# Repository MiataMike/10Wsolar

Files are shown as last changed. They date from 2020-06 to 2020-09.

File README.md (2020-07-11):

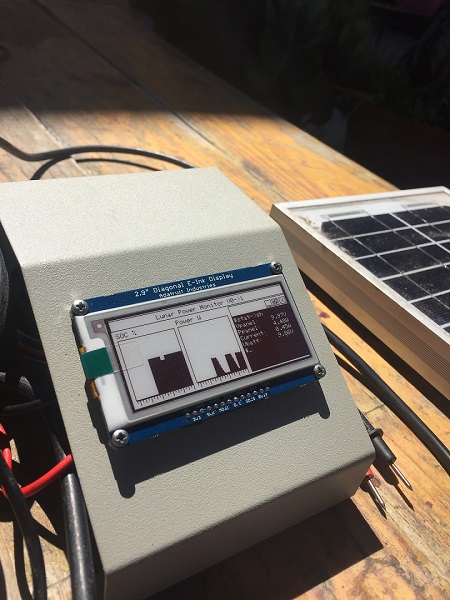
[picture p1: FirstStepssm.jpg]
image of charger


# 10Wsolar
This project is a solar power converter for charging the 12V battery in my truck with a 10W solar panel I got from amazon. 
## MPPT control
Solar panels deliver different currents at different voltages, in the specs below we can see it's 0A @ 21V and .57A @ 17.5V.
 The power of the first is 0W and the second is 10W, so we can get more power from our panel if we operate at the optimal voltage.
 The microcontroller will vary the duty cycle of the buck converter, lowering the voltage of the panel from between open circuit voltage and the battery's voltage.
 Additionally, I don't want to overcharge the battery (It's currently directly connected and who knows what rate it's working at) so I'll add some control logic to trickle charge the battery.
 Since I'm a data geek, I've added an SD card so I can monitor the panel's performance over time, and the truck's (hopefully full) state of charge.
 # Parts
 
 ## Voltage sensing
 The voltage sensing is reading the panel's voltage and the battery's voltage. The panel voltage is used in the control loop to calculate the power we're pulling from the panel. The battery voltage is measured to check state of charge.
 I've used high value resistors because this current draw is constant, even at night. The filtering is agressive so I'll need to slow down my control loop and watch out for oscillation.

 ## CPU
 I've wanted to get my feet wet with ARM processors after taking a class on them in college. This processor has a small form factor and low power to boost efficiency.
 
## Buck converter
Thanks TI for making the buck converter component datasheet! I've chosen values from the panel specs below, but added a much larger inductor in case my frequency needs to go down, or I want to convert much smaller currents
I've added a backup diode in case the syncronous switching doesn't work out. 
 
## current sensing
TI also makes a great chip for monitoring the voltage across a shunt. Doing this with a single ended ADC would be a pain, and it comes with built in filtering and gain. 

## 3.3V converter
Thanks Collin Winans, I'm using his design for a 3.3V buck converter to supply power to the circuit. Most of the symbols in this design are his too.
This should be a very efficeint option since we're stepping down all the way from 12V, which would be a lot of energy to burn in a linear regulator.

## MPPT algorithm
At first, I may just close the top switch and collect data on what the panel does when it's connected directly. This would give me a baseline
From there, I would write code that calculates and optimizes the power coming from the panel. 
The hill climbing algorithm that changes direction every time it detects a drop in power should do nicely. 
Some other features I'd like to add are:
- sleeping at night
- characterizing the panel (V vs A)
- voltage cutoff and derating based on battery voltage
- bitcoin mining to prevent overcharge (not on a Cortex-F0, but still)

## panel specs
- 21V open circuit
- 17.5V @peak power
- .57A 	@peak power
- stylish aluminum frame

# Routing considerations

## Current carrying
I'm designing this around a 1A nominal current, which is more than the 10W panel should put out on the 12V bus. Using a trace width calculator w/ 10C rise @ 1oz/ft^2, I get 11mil traces minimum. Lower trace resistance decreases losses, so this is a minimum

## Overall layout
when designing power electronics, it's important to imagine the current path and ground returns. Can you tell which way I routed it?

## Coil placement
 Big Bob is on the top, a horizontally mounted toroidal coil. On the bottom there's a bobbin wound inductor for the 5V supply.
 The direction of the magnetic field around the bobbin creates a toroid whose axis is normal to the board while the toroid creates a field in a circle along the plane of the board.
 Having these fields at 90 degrees should minimize coupling.

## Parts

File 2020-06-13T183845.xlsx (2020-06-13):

Index | Quantity | Part Number | Manufacturer Part Number | Description | Customer Reference | Available | Backorder | Unit Price | Extended Price USD
1 | 1 | M8843-ND | 2319-H-RC | FIXED IND 390UH 5A 72 MOHM TH |  | 1 | 0 | 3.99 | 3.99
2 | 2 | SSM3K329RLFCT-ND | SSM3K329R,LF | MOSFET N CH 30V 3.5A 2-3Z1A |  | 2 | 0 | 0.41 | 0.82
3 | 1 | LTC1255CS8#PBF-ND | LTC1255CS8#PBF | IC GATE DRVR HIGH-SIDE 8SOIC |  | 1 | 0 | 7.61 | 7.61
4 | 2 | AS-210MPD-ND | AS-210 | PANEL MOUNT DIN SOCKET ANTI-SPLA |  | 2 | 0 | 7.81 | 15.62
5 | 10 | 118-CR0805-JW-203ELFCT-ND | CR0805-JW-203ELF | RES SMD 20K OHM 5% 1/8W 0805 |  | 10 | 0 | 0.018 | 0.18
6 | 10 | RMCF0805JT120KCT-ND | RMCF0805JT120K | RES 120K OHM 5% 1/8W 0805 |  | 10 | 0 | 0.019 | 0.19
7 | 10 | 399-4925-1-ND | C0805C106K8PACTU | CAP CER 10UF 10V X5R 0805 |  | 10 | 0 | 0.117 | 1.17
8 | 1 | 296-41286-1-ND | LM22674MRX-5.0/NOPB | IC REG BUCK 5V 500MA 8SOPWR |  | 1 | 0 | 2.92 | 2.92
9 | 10 | 490-12457-1-ND | GRT31CR61H106ME01L | CAP CER 10UF 50V X5R 1206 |  | 10 | 0 | 0.349 | 3.49
10 | 2 | 732-11924-1-ND | 870235675007 | WCAP-PT5H ALUMINUM POLYMER CAP |  | 2 | 0 | 2.01 | 4.02
11 | 2 | RL12T.010JCT-ND | RL1220T-R010-J | RES 0.01 OHM 5% 1/4W 0805 |  | 2 | 0 | 0.36 | 0.72
12 | 1 | 296-46096-1-ND | INA225AIDGKR | IC MONITOR PWR/CUR BIDIR 8VSSOP |  | 1 | 0 | 2.04 | 2.04
13 | 2 | RNCF0805AKT10R0CT-ND | RNCF0805AKT10R0 | RES 10 OHM 0.05% 1/8W 0805 |  | 2 | 0 | 0.97 | 1.94
14 | 2 | 399-1159-1-ND | C0805C103K1RACTU | CAP CER 10000PF 100V X7R 0805 |  | 2 | 0 | 0.1 | 0.20
15 | 1 | SDR1105-151KLCT-ND | SDR1105-151KL | FIXED IND 150UH 1.2A 500MOHM SMD |  | 1 | 0 | 0.97 | 0.97
16 | 2 | 1727-3848-1-ND | PMEG6010CEH,115 | DIODE SCHOTTKY 60V 1A SOD123F |  | 2 | 0 | 0.42 | 0.84
17 | 1 | 609-5505-ND | 68000-113HLF | CONN HEADER VERT 13POS 2.54MM |  | 1 | 0 | 0.73 | 0.73
18 | 1 | 1528-1963-ND | 1952 | JUMPER WIRE M TO F 12" 28AWG |  | 1 | 0 | 3.95 | 3.95
19 | 1 | 1528-1028-ND | 1028 | 2.9" RED/BLACK/WHITE EINK DSPLY |  | 1 | 0 | 34.95 | 34.95
20 | 1 | 1528-2385-ND | 2756 | TEENSY 3.2 K20 EVAL BRD |  | 1 | 0 | 24.94 | 24.94
21 | 2 | S7012-ND | PPTC141LFBN-RC | CONN HDR 14POS 0.1 TIN PCB |  | 2 | 0 | 0.91 | 1.82
22 | 1 | CN645R-25-ND | 1569-16-1-0500-004-1-TS | HOOK-UP STRND 16AWG 300V RED 25' |  | 1 | 0 | 9.52 | 9.52
23 | 1 | CN642B-25-ND | 1569-16-1-0500-001-1-TS | HOOK-UP STRND 16AWG 300V BLK 25' |  | 1 | 0 | 9.52 | 9.52
24 | 10 | A27824CT-ND | 3-350819-2 | CONN QC RCPT 14-16AWG 0.250 |  | 10 | 0 | 0.255 | 2.55
25 | 10 | WM17242-ND | 0192030470 | CONN RING CIRC 14-16AWG #8 CRIMP |  | 10 | 0 | 0.129 | 1.29
26 | 3 | WM13853-ND | 0192030388 | CONN RING CIRC 14-16AWG #10 |  | 3 | 0 | 0.14 | 0.42
27 | 3 | ED1501-ND | ED550/2DS | TERM BLK 2P TOP ENTRY 3.5MM PCB |  | 3 | 0 | 1.06 | 3.18
28 | 1 | HM3090-ND | 1456CE3WHBU | CONSOLE ALUMINUM 4.18"L X 5.75"W |  | 1 | 0 | 23.65 | 23.65
29 | 1 | RPC3080-ND | HG-17 | GROMMET 0.315" ELASTOMER BLACK |  | 1 | 0 | 0.68 | 0.68
30 | 4 | 36-400-ND | 400 | ROUND SPACER #4 ALUMINUM 3/8" |  | 4 | 0 | 0.18 | 0.72

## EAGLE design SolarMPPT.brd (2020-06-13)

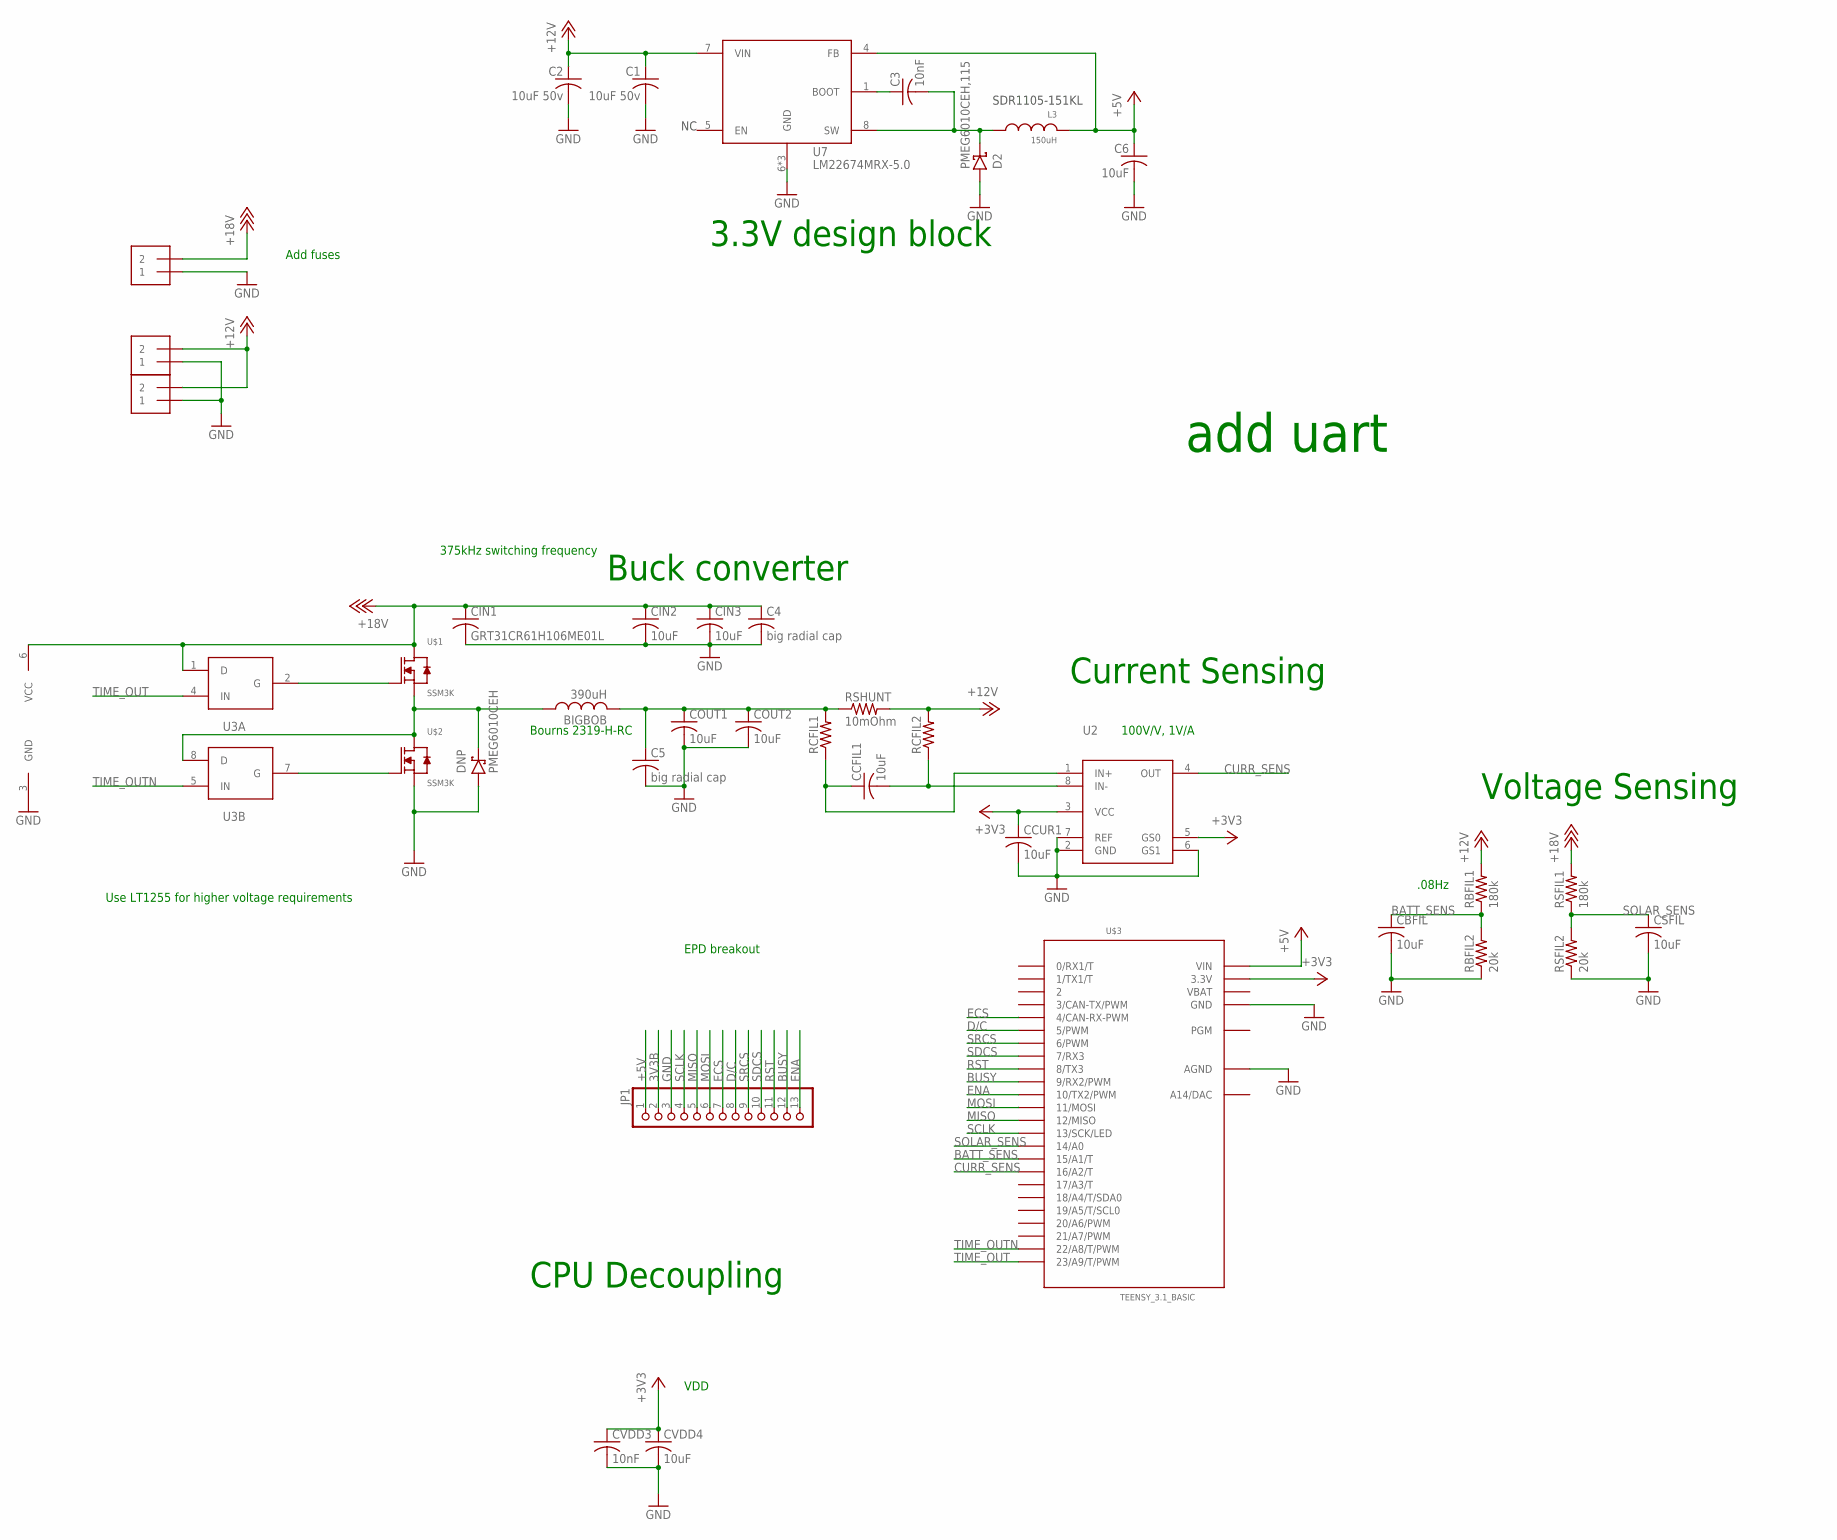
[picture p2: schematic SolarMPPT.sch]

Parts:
BIGBOB: 390uH; TJ6-U2
C1: 10uF 50v; C0805; PARTNO UMK212BJ105KG-T
C2: 10uF 50v; C1206; PARTNO GRM31CR71H475KA12L
C3: 10nF; C0805; PARTNO GRM216R71H103KA01D
C4, C5: big radial cap; C050-024X044
C6: 10uF; C0805; PARTNO GRM21BR61E106KA73L
CBFIL: 10uF; C0805
CCFIL1: 10uF; C0805
CCUR1: 10uF; C0805
CIN1: GRT31CR61H106ME01L; C1206
CIN2, CIN3: 10uF; C1206
COUT1, COUT2: 10uF; C1206
CSFIL: 10uF; C0805
CVDD3: 10nF; C0805
CVDD4: 10uF; C0805
D2: PMEG6010CEH,115; SOD-123; PARTNO PMEG6010CEH115
DNP: PMEG6010CEH; SOD-123
J2, J3, J6: 1X2-3.5MM
JP1: PINHD-1X13; 1X13
L3: 150uH; SDR1105; PARTNO SDR1105-151KL
RBFIL1: 180k; R0805
RBFIL2: 20k; R0805
RCFIL1, RCFIL2: R-US_R0805; R0805
RSFIL1: 180k; R0805
RSFIL2: 20k; R0805
RSHUNT: 10mOhm; R1206
U2: INA225VSSOP; VSSOP-8
U3: LTC1155; LT-SOL8
U7: LM22674MRX-5.0; SOIC-8-POWERPAD; PARTNO LM22674MRX-5.0/NOPB
U$1, U$2: SSM3K; SOT-23-MOSFET
U$3: TEENSY_3.1_BASIC

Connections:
3V3B: JP1.2
+3V3: CCUR1.1, CVDD3.1, CVDD4.1, U2.3 (VCC), U2.5 (GS0), U$3.3.3V, U$3.3.3V1 (3.3V)
+5V: C6.1, JP1.1, L3.P$1, U7.4 (FB), U$3.VIN
+12V: C1.1, C2.1, J2.2, J3.2, RBFIL1.2, RCFIL2.2, RSHUNT.2, U7.7 (VIN)
+18V: C4.1, CIN1.1, CIN2.1, CIN3.1, J6.2, RSFIL1.2, U3.1 (D), U3.6 (VCC), U$1.D
BATT_SENS: CBFIL.1, RBFIL1.1, RBFIL2.2, U$3.15/A1 (15/A1/T)
BOOT_5V2: C3.1, U7.1 (BOOT)
BUSY: JP1.12, U$3.9 (9/RX2/PWM)
CURR_SENS: U2.4 (OUT), U$3.16/A2 (16/A2/T)
D/C: JP1.8, U$3.5 (5/PWM)
ECS: JP1.7, U$3.4 (4/CAN-RX-PWM)
ENA: JP1.13, U$3.10 (10/TX2/PWM)
GND: C1.2, C2.2, C4.2, C5.2, C6.2, CBFIL.2, CCUR1.2, CIN1.2, CIN2.2, CIN3.2, COUT1.2, COUT2.2, CSFIL.2, CVDD3.2, CVDD4.2, D2.A, DNP.A, J2.1, J3.1, J6.1, JP1.3, RBFIL2.1, RSFIL2.1, U2.2 (GND), U2.6 (GS1), U2.7 (REF), U3.3 (GND), U7.6 (GND), U7.PAD (GND), U7.PAD1 (GND), U$2.S, U$3.AGND, U$3.GND, U$3.GND1 (GND)
MISO: JP1.5, U$3.12 (12/MISO)
MOSI: JP1.6, U$3.11 (11/MOSI)
unnamed: U3.2 (G), U$1.G
unnamed: CCFIL1.2, RCFIL2.1, U2.8 (IN-)
unnamed: CCFIL1.1, RCFIL1.1, U2.1 (IN+)
unnamed: BIGBOB.1, DNP.K, U3.8 (D), U$1.S, U$2.D
unnamed: U3.7 (G), U$2.G
unnamed: BIGBOB.2, C5.1, COUT1.1, COUT2.1, RCFIL1.2, RSHUNT.1
RST: JP1.11, U$3.8 (8/TX3)
SCLK: JP1.4, U$3.13 (13/SCK/LED)
SDCS: JP1.10, U$3.7 (7/RX3)
SOLAR_SENS: CSFIL.1, RSFIL1.1, RSFIL2.2, U$3.14/A0
SRCS: JP1.9, U$3.6 (6/PWM)
SW_5V2: C3.2, D2.K, L3.P$2, U7.8 (SW)
TIME_OUT: U3.4 (IN), U$3.23/A9 (23/A9/T/PWM)
TIME_OUTN: U3.5 (IN), U$3.22/A8 (22/A8/T/PWM)
VBAT: U$3.VBAT

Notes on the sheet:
VDD
.08Hz
100V/V, 1V/A
375kHz switching frequency
Use LT1255 for higher voltage requirements
Bourns 2319-H-RC
Voltage Sensing
Current Sensing
CPU Decoupling
3.3V design block
Buck converter
SDR1105-151KL
Add fuses
add uart
EPD breakout

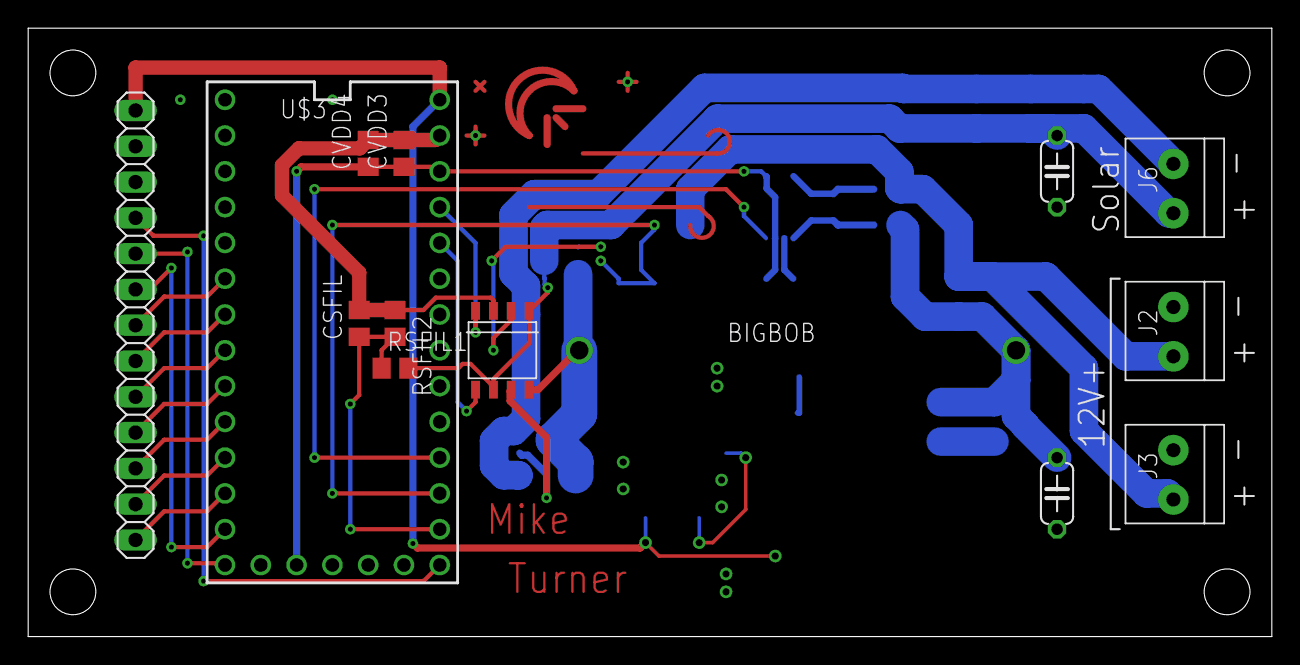
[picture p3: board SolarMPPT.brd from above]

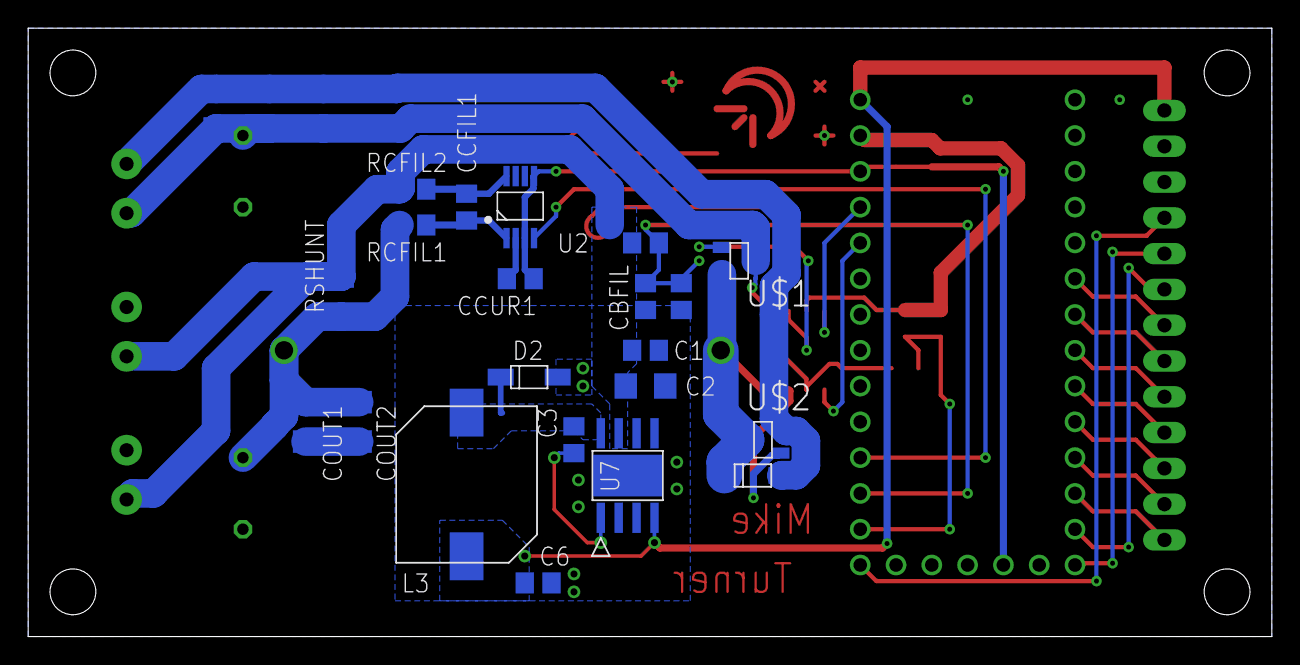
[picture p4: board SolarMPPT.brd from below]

Board: 2 copper layers, 88.3 x 43.2 mm, 38 parts (24 on the bottom side), 28 nets.

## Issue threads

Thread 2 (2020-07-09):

Current reads .02 when no current is flowing

MiataMike, 2020-07-09:

MiataMike, 2020-07-11:
Slam dunk of a fix, but I'll wait to close this for semantics' sake

MiataMike, 2020-07-25:
Current goes to 0 at night, closing
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

Closed 2020-07-25.

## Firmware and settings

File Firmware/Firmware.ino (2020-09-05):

#include <Adafruit_GFX.h>    // Core graphics library
#include "Adafruit_EPD.h"
#include "gauges.h"
#include "reading.h"
#include "control.h"
#include "math.h"
#include "TimeLib.h"
#include <SD.h>


#define EPD_CS      4
#define EPD_DC      5
#define SRAM_CS     6
#define EPD_RESET   8 // can set to -1 and share with microcontroller Reset!
#define EPD_BUSY    9 // can set to -1 to not use a pin (will wait a fixed delay)
#define SD_CS       7

int chartData1[85];
String chartTitle1 = "Battery V";
int chartData2[84];
String chartTitle2 = "Power W";
Adafruit_IL0373 display(296, 128, EPD_DC, EPD_RESET, EPD_CS, SRAM_CS, EPD_BUSY);
Graph SOCgraph(5, 32, 86,86,"SOC %", &display);
Graph POWgraph(96, 32, 86,86, "Power W", &display);
float Vbatt = -1;
float Vpan = -1;
float Abatt = -1;

int duty = 0;

File datalog;

elapsedMillis timeSinceDisplay;
#define DisplayPeriodMillis 60000*5
elapsedMillis timeSinceCmd;
#define CmdPeriodMillis 100 // TODO tune this

#define hr 9
#define minute 21
#define sec 0
#define day 20
#define month 8
#define yr 2020



void setup() {
  //setTime(hr,minute,sec,day,month,yr);Soldered on RTC, Synced with NTP
  // put your setup code here, to run once:
  Serial.begin(9600);
  analogReadRes(16);
  delay(1000);
  
  for(int i = 0; i<84; i++)
  {
    chartData1[i] = 0;
    //chartData1[i] = 42*cos(i*6.28/42)+42;
    //Serial.println(chartData1[i]);
  }
    for(int i = 0; i<84; i++)
  {
    chartData2[i] = 0;
    //chartData2[i] = 42*sin(i*6.28/42)+42;
    //Serial.println(chartData2[i]);
  }
  SOCgraph.updateData(chartData1);
  POWgraph.updateData(chartData2);

  display.begin();
  SD.begin(SD_CS);
  initControl();
}

void loop() {
  // put your main code here, to run repeatedly:

while(1)
{
  if(timeSinceDisplay > DisplayPeriodMillis)
  {
    timeSinceDisplay -= DisplayPeriodMillis;
    SOCgraph.updateData2(84, (int)(Vbatt * 84 / 15.0));
    POWgraph.updateData2(84, (int)(Vbatt * Abatt * 84/13.0));

    display.clearBuffer();
    drawWindow(&display);
    SOCgraph.draw();
    POWgraph.draw();
    drawTerminal(Vbatt, Vpan, Abatt, &display);
    display.display();
    datalog = SD.open("datalog.csv", FILE_WRITE);
    if (datalog)
    {// Time, Vpanel, Abatt, Vbatt, duty
      datalog.print(now());
      datalog.print(",");
      datalog.print(Vpan);
      datalog.print(",");
      datalog.print(Abatt);
      datalog.print(",");
      datalog.print(Vbatt);
      datalog.print(",");
      datalog.println(duty);  
      datalog.close();
    }
  }

  if(timeSinceCmd > CmdPeriodMillis)
  {
    timeSinceCmd -= CmdPeriodMillis;
    Vpan = readSolar();
    Abatt = readCurr();
    Vbatt = readBatt();
    Serial.println(Vpan);
    Serial.println(Abatt);
    Serial.println(Vbatt); 
    Serial.println(duty);
    Serial.println("_________");
    duty = highPower(Vbatt, Abatt, duty);
    analogWrite(HighsidePin, duty);

  }
  
}
}//end loop()

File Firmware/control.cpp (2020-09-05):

#include "control.h"
#include "arduino.h"

int initControl()
{
  pinMode(HighsidePin, OUTPUT);
  analogWriteResolution(6);
  analogWriteFrequency(HighsidePin, 1500000);
	analogWrite(HighsidePin, 0);
	//digitalWrite(HighsidePin, HIGH);
	return 0;
}

#define Vcutoff 14.4
void updateControl(float Vbus)
{
	if (Vbus < Vcutoff)
	{
		digitalWrite(HighsidePin, HIGH); //allow charging
	}
	else
	{
		digitalWrite(HighsidePin, LOW);// turn off in all other cases
	}
	return;
}

int highPower(float Vbus, float Abatt, int duty)
{
  static float lastPow = 0; // filter this?
  static bool upLast = false; // hillclimbing state
  if(Abatt < .02){return dutyUp(duty);} // keep it from getting stuck
  else if(Vbus > 13.7){return dutyDown(duty);}// don't overcharge
  else if(lastPow > Vbus*Abatt)//if it got worse
  {
    if(upLast){duty = dutyDown(duty);}//and it was going up, go down
    else{duty = dutyUp(duty);}        //if it was going down, go up
    upLast = !upLast;             //change direction
  }
  else                            //if it got better
  {
    if(upLast){duty = dutyUp(duty);}  //keep going up
    else{duty = dutyDown(duty);}      //GJ 
  }
  lastPow = Vbus*Abatt;
  return duty;
}


//Bounds checking I didn't want to include in the function
#define dutyMin 0 //so it doesnt get lost
int dutyDown(int duty)
{
  if (duty <= dutyMin)
  {
    duty = dutyMin;
  }
  else{duty--;}
  return duty;
}

#define dutyMax 64
int dutyUp(int duty)
{
  if (duty >= dutyMax)
  {
    duty = dutyMax;
  }
  else{duty++;}
  return duty;
}

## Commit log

2020-05-30 Adding eagle schematic and Buck calculator
    [SolarMPPT.sch, TI_Buck calc.xlsx]
2020-05-30 Added LT1255 gate driver and MOSFETs
    [SolarMPPT.sch]
2020-05-30 finished Buck component selection
    [SolarMPPT.sch]
2020-05-30 Added decoupling caps, cleaned up schematic, ready for review
    [SolarMPPT.sch]
2020-05-30 Updated 'documentation' and spreadsheet
    [TI_Buck calc.xlsx]
2020-05-31 created brd file and sorted into categories
    [SolarMPPT.brd, SolarMPPT.sch]
2020-05-31 placed components in rough location. Might remap ADC pins for routing
    [SolarMPPT.brd]
2020-05-31 Did power routing and added terminals
    [SolarMPPT.brd, SolarMPPT.sch]
2020-06-07 added teensy, removed SD
    [SolarMPPT.brd, SolarMPPT.sch]
2020-06-07 removed 3.3v regulator (using teensy onboard)
    [SolarMPPT.brd, SolarMPPT.sch]
2020-06-09 added mounting holes, art, and generally cleaned up before ordering!
    [SolarMPPT.brd, SolarMPPT.sch]
2020-06-09 Went back and forth with osh getting it right, this version was ORDERED
    [SolarMPPT.brd, SolarMPPT.sch]
2020-06-13 Created digikey cart, updated schematic with components
    [2020-06-13T183845.xlsx, SolarMPPT.brd, SolarMPPT.sch]
2020-07-09 Added datalog of 24 hours!
    [DATALOG.CSV]
2020-07-11 I suspect this is the fix
    [Firmware.ino]
2020-09-05 Moved to separate loops for ctrl and display so ctrl loop reacts faster
    [DATALOG_1.CSV, DATALOG_2.CSV]
2021-06-06 added datalogs
    [DATALOG1.CSV, DATALOG2.CSV]
